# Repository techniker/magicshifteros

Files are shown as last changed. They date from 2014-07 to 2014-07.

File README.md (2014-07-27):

# MagicShifterOS #

Everything you need to modify and customize your MagicShifter

The most important directories are:

### /Case ###
All source (OpenSCAD + dxf) and STL files for the case and the first MagicShifter accessory: a bike mount.

### /Electronics ###
The original EAGLE design files of the MagicShifter PRO board (CC BY-NC-SA 3.0 http://creativecommons.org/licenses/by-nc-sa/3.0/), a PDF of the scematics and the BOM (Bill of Material) that documents every single resistor, capacitor, connector and IC I used in the design. I chose the CC BY-NC-SA to prevent crappy rip off copies. We use very high quality components from Osram, Cree, Texas Instruments, Freescale, austriamicrosystems, etc. and I fear in cheap MagicShifter clones these will be replaced by inferior replacements. If you make a true derivative of the design I will happily grant almost any exception to the license (free of charge of course) since I was hoping to spark a new wave of small, smart, embedded ultra low power systems for gaming, fashion & lighting with the release of my MagicShifter design :) 

I tried to give full credit to all the open source designs that influenced the MagicShifter design. If I forgot to reference any project please send me an email so that I may correct that mistake.

### /Firmware ###
Here is the code and the Makefile (generously written by Clifford Wolf http://www.clifford.at/). 

To build the firmware you have to copy the unzipped arduino software into a (not version controlled) "arduino" subfolder in the "Firmware" folder to compile the firmware yourself. Arduino is required since we use the Arduino USB implementation. 

If you don't want to build the firmware yourself you can use the precompiled HEX file in the "precompiled" subdirectory.

### /Software 
in the python subfolder you can find the tools for uploading custom images and custom firmware

* * *

please report any bugs you find in the ticket system or just send me a mail to:

wizards23+magicshifter@gmail.com

* * *

greetings from the future!

Philipp aka wizard23 aka babygiraffe

:: open source hardware/magic

:: http://magicshifter.net/

:: http://metalab.at/

Any sufficiently advanced technology is indistinguishable from a MagicShifter.

--Arthur C. Clarke

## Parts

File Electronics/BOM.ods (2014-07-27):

Nr | Name | Qty | Type | desc | rating | footprint | manufacturer | manuf. nr.
1 | BCENT, BON | 2 | OTHER | tactile switch, side, high reliability | B3F-3122 | B3F-31XX | Omron | B3F-3122
2 | BOFF, BRESET | 2 | OTHER | tactile switch, ultrasmall | B3U-1000P | B3U-XXXX | Omron | B3U-1000P
3 | C1, C2, C3, C4, C201, C301, C601, C602, C901, C903, C904, C905 | 12 | Capacitor |  | 100nF/25V/X7R | C0603
4 | C102, C103 | 2 | Capacitor |  | 2.2uF/16V/X7R | C0805
5 | C104, C105 | 2 | Capacitor |  | 10nF/25V/X7R | C0603
6 | C106, C304 | 2 | Capacitor |  | 47nF/25V/X7R | C0603
7 | C5, C6, C101, C661, C662, C663, C664, C665, C666, C701, C702, C801, C802 | 13 | Capacitor |  | 1uF/16V/X7R | C0603
8 | C7, C8 | 2 | Capacitor |  | 22pF/50V/NP0 | C0603
9 | C803 | 1 | Capacitor |  | 22uF/6.3V/ | C0805
10 | C902 | 1 | Capacitor |  | 4.7uF/10V/X7R | C0805
11 | D1, D2 | 2 | Diode | DUAL DIODE | BAV170,215 | SOT23 | NXP | BAV170,215
12 | FET1, FET3 | 2 | IC | N-mosfet | N Mosfet | SOT23 | Infineon | BSS123
13 | FET2 | 1 | IC | N/P dual mosfet | N/P Dualmosfet | SOT363 | DiodesZetex | DMG1016UDW-7
14 | LEDCHRG, LEDDEBUG | 2 | Diode | Blue LED | Blue, >40mcd@20mA | LED0603
15 | LEDFULL | 1 | Diode | Green LED | Green, >40mcd@20mA | LED0603
16 | LEDIR | 1 | Diode | Infrared LED | IR | LED1206 | Everlight | HIR11-21C/L11/TR8
17 | LEDON, LEDTX | 2 | Diode | Red LED | Red, > 40mcd@20mA | LED0603
18 | LEDRGB1 – LEDRGB16 | 16 | Diode | RGB LED | RGB | 5050 | Cree | CLV6A-FKB-CK1P1G1BB7R3R3
19 | LEDRX | 1 | Diode | Yellow LED | Yellow, >40mcd@20mA | LED0603
20 | LEDUV | 1 | Diode | UV LED | UV | LED1206 | Bivar | SM1206UV-395-IL
21 | LEDWHITE | 1 | Diode | White LED | OSLON | OSLON | Osram OS | LUW CN5M-GAHA-5P7R-1
22 | R1, R4, R6, R103, R108, R114, R119, R302, R805 | 9 | Resister |  | 1K/5%/0.1W | R0603
23 | R101, R102, R802 | 3 | Resister |  | 22R/5%/0.1W | R0603
24 | R104 | 1 | Resister |  | 47K/5%/0.1W | R0603
25 | R107, R110 | 2 | Resister |  | 22K/5%/0.1W | R0603
26 | R111, R116, R118, R120, R201, R202, R603, R804 | 8 | Resister |  | 100K/5%/0.1W | R0603
27 | R112 | 1 | Resister | ref Va | 330K/1%/0.1W | R0603
28 | R113 | 1 | Resister | ref Vb | 560K/1%/0.1W | R0603
29 | R13, R14, R15 | 3 | Resister |  | 330R/5%/0.1W | R0603
30 | R2, R3, R106, R703, R704, R705 | 6 | Resister |  | 10K/5%/0.1W | R0603
31 | R601, R602 | 2 | Resister | rgb ref | 2K/1%/0.1W | R0603
32 | R701 | 1 | Resister | uv ref | 15K/1%/0.1W | R0603
33 | R702 | 1 | Resister | white ref | 6K8/1%/0.1W | R0603
34 | R8, R9, R105, R117 | 4 | Resister | R105: chrgref; R117: tchrgref | 4K7/1%/0.1W | R0603
35 | R801 | 1 | Resister |  | 1M/5%/0.1W | R0603
36 | R803 | 1 | Resister |  | 47R/5%/0.1W | R0603
37 | UCACCEL | 1 | IC | 3 Axis Accelerometer | Accelerometer | QFN-16 | Freescale | MMA8452QT
38 | UCATMEL | 1 | IC | uC, Atmega32U4-MU | uC | QFN-44 | Atmel | Atmega32U4-MU
39 | UCCHRG | 1 | IC | Lipo Charger | Lipo charger | SOT23-5 | Microchip | MCP73831T-2ACI/OT
40 | UCEEPROM | 1 | IC | SPI EEPROM 1MBt | SPI EEPROM | SOIC-8/150mil | Microchip | SST25VF080B-80-4I-SAE
41 | UCL1, UCL2 | 2 | IC | LED Driver | LED Driver | SOT23-6 | Adv. Analogic Tech. | AHK3292IGU-T1
42 | UCLSEN | 1 | IC | RGBV Light Sensor with Prox. | RGBV Sensor | FN-6 | AMS | TCS37717FN
43 | UCRGB1, UCRGB2 | 2 | IC | 24 Ch. Led Driver | LED Driver | QFN-32 | Texas Instruments | TLC5947RHBT
44 | UCRTC | 1 | IC | I2CTM Real-Time Clock | I2C_RTC | MSOP-8 | Microchip | MCP79410-I/MS
45 | UCVRG | 1 | IC | VOLTAGE REG | VREG | SOT23-5 | Microchip | MCP1824T-3302E/OT
46 | XLIPO1 | 1 | Connector | Through-hole type shrouded header, SIDEENTRY, 2mm | S 2B-PH-K-S | pin_2x2mm | JST | S 2B-PH-K-S
47 | XUSB | 1 | Connector | USB micro AB conn, SMD | USBAB | SMD | FCI | 10104111-0001LF
48 | Y1 | 1 | OTHER | Crystal, SMD-5X3 | 8MHz/30ppm/12pF/ | SMD-5X3.2mm | Interquip | 5RCA08000123TF80Q3
49 | Y2 | 1 | OTHER | Crystal, THRU-HOLE | 32.768kHz/20ppm/12pF/50K | NC26LF | Fox Electronics | NC26LF-327

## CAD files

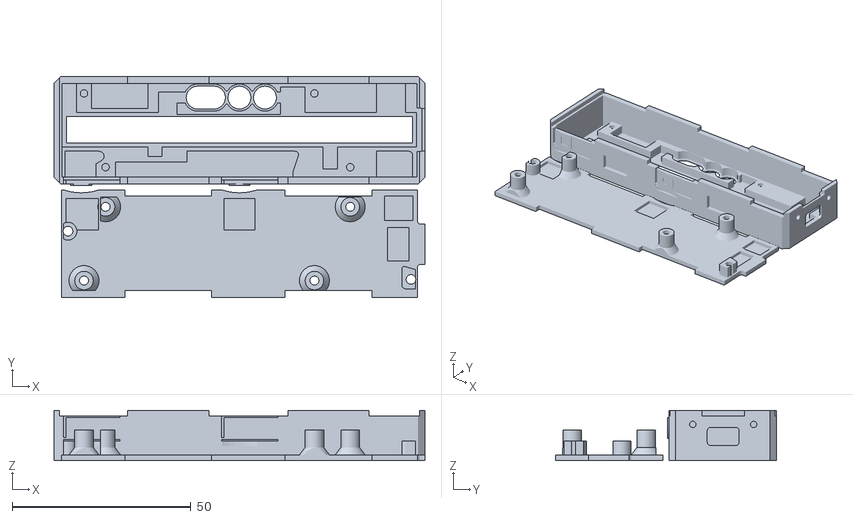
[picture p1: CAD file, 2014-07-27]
Case/magicshifter_case_100.stl
103.7 x 61.8 x 14.0

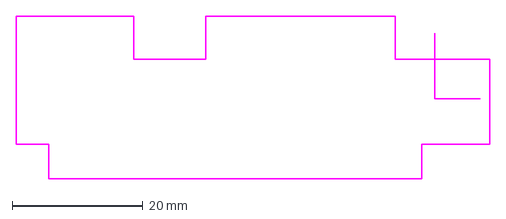
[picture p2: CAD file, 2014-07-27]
Case/magicshifter_case_87.dxf
72.4 x 24.9 mm

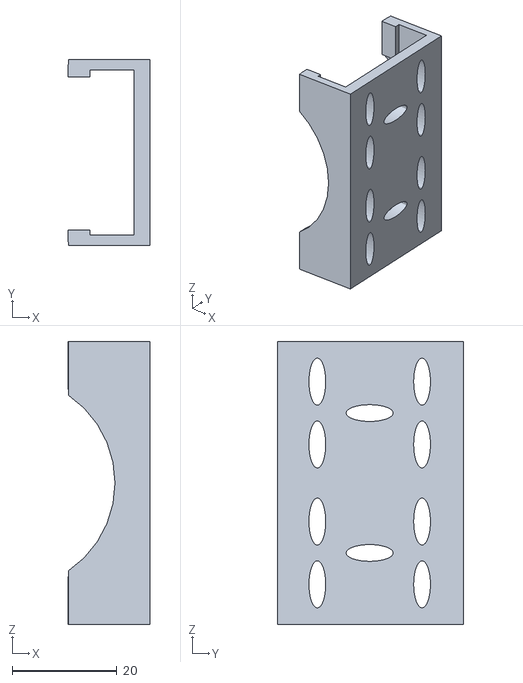
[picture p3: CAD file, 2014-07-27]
Case/magicshifter_case_95_bikesnap.stl
15.6 x 35.5 x 54.0

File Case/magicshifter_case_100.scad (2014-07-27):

/*
 * MagicShifter Case Prototype
 * Copyright (C) 2013  Philipp Tiefenbacher <wizards23@gmail.com>
 *
 * This program is free software; you can redistribute it and/or modify
 * it under the terms of the GNU General Public License as published by
 * the Free Software Foundation; eitd2her version 2 of the License, or
 * (at your option) any later version.
 *
 * This program is distributed in the hope that it will be useful,lp
 * but WITHOUT ANY WARRANTY; without even the implied warranty of
 * MERCHANTABILITY or FITNESS FOR A PARTICULAR PURPOSE.  See the
 * GNU General Public License for more details.
 */

// the name of the file that is used for all 2D geometry
dxfFileName = "magicshifter_case_100.dxf";

// if true build plate will be generated; if false assembled model is generated 	
forPrint = true;

preview = false;

// set to true or false depending on what part you want to make
generateBottomPart	= true;
generateTopPart 	= true;
generateButtonCover = false;

// print quality/detail level of cirlces 
$fn=preview ? 8 : 32;

// height of the bottom layer of the bottom part (which is the side you see when you look at the LEDs
floorH=0.5;

// height of the 2nd layer from the bottom (the layer the pcb rests on); it has holes where components are on the bottom side of the PCB

foilH = 0.3;
pcbToFloorH = 2.5 + 0.75 + foilH - 0.6;

// height of the magicshifter pcb (without components)
pcbHeight=1.75;

// the height of the lid (lid == topPart)
lidH = 1.6;

lidHollow = 1.1;

// total height of assembled case
totalH=14; 

pillarCutH = 5.5;


// should be larger than the largest dimension of the case (used in the 2D to 3D conversion), no need to change this 
infSize = 500;

///////////////////////////////////////////////////////////////////////

// height of the button cover (derived from totalH and the other heights)
buttonH = totalH - (pcbToFloorH+floorH+pcbHeight+lidH);

pillarH = totalH-(pcbToFloorH+floorH+pcbHeight+0.3);

////////////////////////////////////////
// the actual parts
////////////////////////////////////////

// bottom part (the one the pcb is in facing with the LEDs down and the 


*union()
{
	translate([0,0*32,0]) render() mirror([0,1,0]) topPart();
	translate([0,1*32,0]) render() mirror([0,1,0]) topPart();
	translate([0,2*32,0]) render() mirror([0,1,0]) topPart();
	translate([0,3*32,0]) render() mirror([0,1,0]) topPart();
}

*union()
{
	translate([0,0*32,0]) render() bottomPart();
	translate([0,1*32,0]) render() bottomPart();
	translate([0,2*32,0]) render() bottomPart();
	translate([0,3*32,0]) render() mirror([0,1,0]) topPart();
	
	translate([-20,0,0]) rotate([0,0,90]) render() mirror([0,1,0]) topPart();
	
	translate([-20-32,0,0]) rotate([0,0,90]) render() mirror([0,1,0]) topPart();
}



*rotate([0,0,90]) for (i = [0:1])
{
	translate([i*64, 0,0]) completeCase();
}

translate([65, -20,0]) rotate([0,0,90]) completeCase();

// button cover (TODO: assembled view of this)
if (generateButtonCover) extrudeLayer("buttoncover", buttonH);




module completeCase()
{
	render()

	rotate ([0,0,90])
	{
		if (generateBottomPart) bottomPart();
		
		// top part (the lid with the pillars); top part is mirrored to make drawing the dxf easier
		if (generateTopPart)
		{
			if (forPrint) translate([0,32,0]) mirror([0,1,0]) topPart();
			if (!forPrint) translate([0,0,totalH]) mirror([0,0,1]) topPart();
		}
	}
}

/////////////////////////////////////////
// main modules
/////////////////////////////////////////

module bottomPart()
{
	difference()
	{
		union()
		{
			// the pcb rests on this 
			extrudeLayer("bottom_floor_pcb", floorH+pcbToFloorH,0);
	
			// main part of case
			difference() 
			{
				// outher shape of case
				union() {
					extrudeLayer("bottom_floor", totalH, 0);
					translate([0,0,pcbToFloorH+floorH+pcbHeight]) fromDXF_XY_XZ("button_text_xy", "button_text_xz");
				}
				// cut out the size of pcb
				extrudeLayer("pcb_cutout", totalH, floorH);
				//#extrudeLayer("button_cutout", totalH, pcbToFloorH+floorH+pcbHeight+0.6);

#translate([0,0,pcbToFloorH+floorH+pcbHeight]) fromDXF_XY_XZ("button_cutout_xy", "button_cutout_xz");
	
				// cut out buttons and USB connector extra space
				//*extrudeLayer("side_cutouts", totalH, floorH+pcbToFloorH+pcbHeight);
				
				// cut out indents in the case where accessories are inteded to snap fit onto
				translate([0,0,totalH/2]) fromDXF_XY_XZ("schnappen_halter_xy", "schnappen_halter_xz");		
			}
		}
		// snap cutouts
		union() 
		{
			translate([0,0,pcbToFloorH+floorH+pcbHeight]) fromDXF_XY_XZ("button_slits_xy", "button_slits_xz");
			// we need this intersection because to limit the cutout to the height of the lid
			*intersection()
			{
				// the cutout on the sides where the lid should snap fit in
				translate([0,0,totalH]) fromDXF_XY_XZ("lid_snap_cut_xy", "lid_snap_cut_xz");
				// limit the cutout to height of lid 
				cubeEx([infSize,infSize,lidH*2], [0,0,0.5], [0,0,totalH-lidH]); 
			}
			// hole in case for USB connector also includes small holes for attaching a string
			// TODO: hackish because of the positioning, clean up
			extrudeLayerLeft("bottom_cut_left_zy", 10, zOffset=floorH+pcbToFloorH+pcbHeight, xOffset=0);
			// cut out the space where the lid fits in on top
			extrudeLayer("lid_cut", totalH, totalH-lidH);
			*translate([0,0,totalH-lidH]) fromDXF_XY_ZY("lidholder_cutout_xy", "lidholder_cutout_zy");
			extrudeLayer("button_freedom", totalH, totalH-(lidH+0.3));
		}

		//#extrudeLayer("button_indent_xy", lidH,pcbToFloorH+floorH);
//#extrudeLayer("button_indent_xz", 3*totalH,-1);
		translate([0,0,pcbToFloorH+floorH+pcbHeight])  fromDXF_XY_XZ("button_indent_xy", "button_indent_xz", $fn=64);


	// screwholes 
		for (pos = cylPositions) {
			translate([pos[0], pos[1], floorH]) {
				cylinder(r= 1.05, h = totalH, center=false);
			}
		}
	}
}

cylPositions = [
//[85.8,9.5],
  [86.803053, 10.45868], // at bowwerbutton
 [92.8355, -10.1573],
 [18.4147, 10.4587],
 //[8.405193, -10.15731],
 [28.405193, -10.15731],
 //[6.34989, -8.25234]. // over reset
];

microButtonPositions = [
[1.418143, -9.839815],
[97.3138, 3.654232]
];



module topPart()
{
	difference() {
		union()
		{
			difference()
			{
				// this intersection is needed to get a clean model
				intersection()
				{
					union()
					{
						// the main part of the lid
						extrudeLayer("lid", 4*lidH,-2*lidH);
						// the small snapping parts on the side
						*fromDXF_XY_XZ("lid_snap_xy", "lid_snap_xz");
						*translate([0,0,lidH]) mirror([0, 0, 1]) fromDXF_XY_ZY("lidholder_xy", "lidholder_zy");
					}
					// limit bottom pat of the lid to lidH
					cubeEx([infSize,infSize,lidH], [0,0,0.5], [0,0,0]); 
				}
				extrudeLayer("lid_hollow", 10,lidH-lidHollow);
			}
			difference()
			{
				extrudeLayer("pillars", pillarCutH,0);
				//extrudeLayer("pillars", totalH-(pcbToFloorH+floorH+pcbHeight),0);
				//extrudeLayer("pillars_cutaway", totalH, pillarCutH);
			}
			intersection()
			{
				
				for (pos = cylPositions) {
					translate([pos[0], pos[1], lidH/2]) cylinder(r1= 4.5+0.3, r2=0, h = 6+0.3);
					translate([pos[0], pos[1], lidH/2]) cylinder(r= 2.6, h = pillarH);
				}

				extrudeLayer("lid_crop", pillarH, 0);
			}
			
		}
		// screwholes and versenkte schraubenkoepfe ;)
		for (pos = cylPositions) {
			translate([pos[0], pos[1], -1]) {
				cylinder(r= 1.25, h = 3*totalH, center=true);
				cylinder(r1= 3.4+0.3, r2= 0, h = 3.4+0.3, center=false);
			}
		}
		for (pos = microButtonPositions) {
			translate([pos[0], pos[1], -1]) {
				cylinder(r= 1.35, h = 3*totalH, center=true);
			}
		}

if (!preview)
{
		extrudeLayer("logo", 1.3,-1, $fn=16);

		extrudeLayer("logo2", 1.3,-1, $fn=16);
}

			extrudeLayer("button_indent_xy", 3*totalH,-1, $fn=64);
	}
}

/////////////////////////////////////////
// helper modules
/////////////////////////////////////////

/* 
constructs a 3D object by extruding the given layers of the dxf file 
layerXY is extruded in Z axis
layerZY is extruded in the X axis
*/
module fromDXF_XY_ZY(layerXY, layerZY)
{
	intersection()
	{
		linear_extrude(convexity = 10, height = infSize, center = true)
			import_dxf(file = dxfFileName, layer = layerXY, convexity = 10, scale=1);
		rotate([0,-90,0]) linear_extrude(convexity = 10, height = infSize, center = true)
			import_dxf(file = dxfFileName, layer = layerZY, convexity = 10, scale=1);
	}
}

module fromDXF_XY_XZ(layerXY, layerXZ)
{
	intersection()
	{
		linear_extrude(convexity = 10, height = infSize, center = true)
			import_dxf(file = dxfFileName, layer = layerXY, convexity = 10, scale=1);
		rotate([90,0,0]) linear_extrude(convexity = 10, height = infSize, center = true)
			import_dxf(file = dxfFileName, layer = layerXZ, convexity = 10, scale=1);
	}
}
module fromDXF_XY_ZY_XZ(layerXY, layerZY, layerXZ)
{
	intersection()
	{

linear_extrude(convexity = 10, height = infSize, center = true)
			import_dxf(file = dxfFileName, layer = layerXY, convexity = 10, scale=1);
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

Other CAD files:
Case/magicshifter_case_87_single.stl
Case/magicshifter_case_87.scad
Case/magicshifter_case_95_bikesnap.scad
Case/magicshifter_case_100.dxf

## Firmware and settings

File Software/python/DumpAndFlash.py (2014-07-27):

import os
from MagicTest import *


if __name__ == '__main__':
	shifterNr = -1
	doDump = True
	doFlash = True	
	doBitmaps = True
	device = ""	

	if (len(sys.argv) >= 2):
		shifterNr = int(sys.argv[1])
	if (len(sys.argv) >= 3):
		device = sys.argv[2]
	if (len(sys.argv) >= 5):
		doDump = int(sys.argv[3])
		doFlash = int(sys.argv[4])
	if (len(sys.argv) < 2):
		print "usage:"
		print "python DumpAndFlash.py nrOfShifter [serialdevice] [doDump (default 1)] [doFlash (default 1)]"
		print "example: DumpAndFlash.py 123 1 1"
		print "the aboce command line would dump and flash the shifters using serial number 123 (increasing it 1 for every shifter"
		exit()

	if (not doDump) and (not doFlash):
		print "don't dump and don't flash...nothing to do" 
		exit()

	while (1):
		pOK("Ready to dump and flash MagicShifter Nr: " + str(shifterNr) + " (ESC to cancel)")
		key = read_single_keypress()
		if (ord(key) == 27):
			exit()

		if (doDump):
			continueDump = 3
		else:
			continueDump = 0
		while (continueDump):
			fi, fo, fe= os.popen3("python MagicTest.py dump " + device)
			stderr = fe.readlines()
			stdout = fo.readlines()
			print stdout[0]
			if (stdout[0].find("NR_COLOR_TESTS") != -1 and stdout[0].find("ACC") != -1 and stdout[0].find("EOD") != -1):
				dumpName = "./dumpof500/shifter_%04d.txt" % (shifterNr)
				pOK("writing dump file: " + dumpName)
				if (os.path.exists(dumpName)):
					pFail("Dump file already exists! " + dumpName)
					exit()
				else:
					file = open(dumpName, 'wt')
					file.write(stdout[0])
					file.close()
					pOK("writing dump complete")
				continueDump = 0
			else:
				pFail("dump not working, press key to continue esc to stop")
				key = read_single_keypress()
				if (ord(key) == 27):
					exit()
				continueDump = continueDump - 1

		dmesgClear()

		if doFlash:
			print "--> Press the RESET button"
			cnt = 0
			while (not dmesgPing()):
					sleep(0.1)
					cnt = cnt + 1
					if (cnt > 1000):
						pFail("Reset Button was not pressed within 100 seconds. Is it broken?")
						exit()
			pOK("Reset Button OK!")
			sleep(1)
			pOK("programming device...")
			if(callProgrammer()):
				pOK("bootloader OK! :)")
			else:
				pFail("USB connection does not work or Bootloader is not responding. :(")
				exit()
			sleep(1)
		
		if (doBitmaps):
			continueBitmaps = 3
			while (continueBitmaps):
				print "Uploading Bitmaps (takes some seconds be patient)"
				fi, fo, fe = os.popen3("./UploadCree.sh " + device)
				#fi, fo, fe = os.popen3("./UploadCree_Makerbot.sh")
				#fi, fo, fe = os.popen3("./UploadCree_Makerbot_small.sh")
				stderr = fe.readlines()
				stdout = fo.readlines()
				print stdout
				countBitmaps = 0
				for line in stdout:
					countBitmaps += line.count("READBACK @sector")
				if (countBitmaps != 18):
					pFail("OH noes uploading bitmaps failed (enter to continue exc to exit) == " + str(countBitmaps))
					key = read_single_keypress()
					if (ord(key) == 27):
						exit()
					continueBitmaps = continueBitmaps - 1;
				else:
					continueBitmaps = 0
			

		shifterNr += 1

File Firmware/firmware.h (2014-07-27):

#ifndef FIRMWARE_H
#define FIRMWARE_H

#define ATMELSTUDIO_HACK

#include <Arduino.h>
#include <EEPROM.h>
//#include <Wire.h>

//#define BABYSHIFTER
//#define NOSERIAL

//#define UNITTEST
//#define DEBUGMODE

// TO prevent accidental blindness by 
#define EYE_FRIENDLY

// customize your own name ;)
#define CUSTOMIZED_NAME "Shifter"

#define LEDS 16
// used for fixed point arithmetic
#define FIXED_SHIFT 8
// make columns longer
#define COLUMNMULTIPLY 2
#define ANIMATIONDELAY 2


// chinese LEDS
//#define COLOR_CODING_GRB
// cree LEDS
#define COLOR_CODING_RGB

#ifdef COLOR_CODING_RGB
	#define CHANNEL_RED 		0
	#define CHANNEL_GREEN 	1
	#define CHANNEL_BLUE 	2
#endif
#ifdef COLOR_CODING_GRB
	#define CHANNEL_RED 		1
	#define CHANNEL_GREEN 	0
	#define CHANNEL_BLUE 	2
#endif

/* Pin definitions */
#ifdef BABYSHIFTER
  #define XAXIS 1
  #define YAXIS 0
  #define ZAXIS 2
    
  #define ledPin 11
  
  #define int1Pin 12 // D7  // Baby Shifter  
  #define int2Pin 13 // B4
  
  #define BTNC 8
  
  #define TXLED1 
  #define TXLED0
#else  
  #define RTCINT_PIN A2
  #define IRPWM_PIN 5 // PC6/pin 31 

  #define XAXIS 0
  #define YAXIS 1
  #define ZAXIS 2
  
  #define ledPin  13
  
  #define int1Pin 8  // Magic Shifter  
  #define int2Pin 9

  #define int3Pin 0 // light sensor

  #define EEPROM_CS_PIN 11
  
  #define BTNC 10
#endif

#define LEDWHITE_PIN 6
#define LEDUV_PIN 1


#define RXLED 17
#define PWRMGT A5
#define PWRMGT_ANALOG_PIN 5
#define LEDTESTER_ANALOG_PIN 2

#define CHRGSTAT_PIN A4
#define TURBOCHRG_PIN 7
//#define SHIFT_OUT_PIN 6

#define AUTOSHUTDOWN_TIME (23*60*1000L)  // shuts down automatically after 5 minutes

#define SHUTDOWN_TIME 2000
#define MODE_EXIT_TIME 2000
#define DEBOUNCE_TIME 15
#define LONG_CLICK_TIME 550

#define BrightnessCtrlTime 600

// TODO
#define DOUBLE_CLICK_TIME 250
#define REWARD_FLASH_LEN 350

#define POWERUP_USER 0
#define POWERUP_USB 1
#define POWERUP_ALERT 2

// global Startup state
extern byte powerupReason;

// global ButtonState
extern long powerBtnPressed;
extern int powerBtnClickedTime;
extern int powerBtnReleased;
extern long centerBtnPressed;
extern int centerBtnClickedTime;
extern int centerBtnReleased;

extern long lastActivity;

// define global LED state
extern uint8_t LEDS_VALUES[];

// global Accelerometer state

extern byte data[6];  // x/y/z accel register data store here
extern int accelCount[3];  // Stores the 12-bit signed value

extern byte orientation;
extern byte orientationFace;
extern byte zTilt;
extern int8_t xTaps, yTaps, zTaps;
extern uint8_t lastTapStatus;
extern byte lastTransientStatus;

//#define SHAKEDEBUG
//#define FRAMEDEBUG
#define LASTINTERRUPTTIMEOUT 8

// rtc state
extern uint8_t initiateRTCReadout;
extern uint8_t rtcBuffer[];

// brightness and mode
extern int ad;
extern uint8_t v;
extern uint8_t MAXMV;
extern bool vChanged;

// light sensor state
extern int cs, rs, gs, bs, ps;
extern int lightSensorValues[5];


union MSColor {
#ifdef COLOR_CODING_RGB
  struct { uint8_t r, g, b; } rgb;
#endif
#ifdef COLOR_CODING_GRB
  struct { uint8_t g, r, b; } rgb;
#endif
  struct { uint8_t ch0, ch1, ch2; } ordered;
  uint8_t channels[3];
	
/*
	public MSColor(uint8_t _r, uint8_t _g, uint8_t _b)
	{
		rgb.r = _r;
		rgb.g = _g;
		rgb.b = _b;
	}
*/ 
 };

// MagicShifter.cc
struct MSBitmapHeader
{
	uint32_t eepromAddr;

	uint8_t pixelFormat;
	uint8_t maxFrame;
	uint8_t frameWidth;
	uint8_t frameHeight;

	uint8_t subType;
	uint8_t firstChar;
	uint16_t animationDelay;
} __attribute__((packed));
	
struct MSBitmap
{
	MSBitmapHeader header;
	MSColor color;
};

extern uint8_t AccelShakeNrOfFrames;
extern uint8_t AccelShakeFrameNr;
extern MSBitmap font16px;
extern MSBitmap font12px;
extern MSBitmap font8px;

//extern uint8_t fontWidth;
//extern uint8_t fontHeight;

void run_bootloader();
void MagicShifter_Init();
void blink(int p1, int p2, int n);
void SetDebugLeds(byte debug, byte rx, byte tx);
uint8_t SerialReadByte();
uint16_t SerialReadWord();
bool MagicShifter_Poll_Menue();
bool MagicShifter_Poll();
void USBPoll();
/*void LoadFont(uint8_t sector);
void PlotFont(uint8_t ascii, uint8_t column, uint8_t startLed);
void PlotText(char *text, uint16_t column, uint8_t startLed);
*/
void LoadBitmap(uint8_t sector, MSBitmap *bitmap);
void PlotBitmapColumn1Bit(const MSBitmap *bitmap, uint16_t absColumn, uint8_t ledIdx);
void PlotBitmapColumn24Bit(const MSBitmap *bitmap, uint16_t absColumn, uint8_t startLed);
void PlotBitmapColumn(const MSBitmap *bitmap, uint8_t frame, uint8_t column, uint8_t startLed);
void PlotText(const MSBitmap *bitmap, char *text, uint16_t column, uint8_t startLed);
void UpdateAccelShakeCurrentColumn();

void startToEndIndex2(int start, int end, int d, int index, int color);
void ackFlash(int r, int g, int b, int iS, int iE, int d1, int d2, int d3);
void debugColor(int r, int g, int b, int iS, int iE, int d);
void UpdateButtons();
void saveMode(int idx);
void saturateRgb(uint8_t &r, uint8_t &g, uint8_t &b);
void SetWhiteLED(uint8_t val);
void SetUVLED(uint8_t val);
void enableLeds(uint8_t val);


void CheckTCS3771(int cycles);
bool VerifyTCS3771Interrupt();
void PickupColor(uint8_t &byte_r, uint8_t &byte_g, uint8_t &byte_b);
void PickupColorEx(uint8_t cycles, uint8_t useLight);
byte xorshift32();


// MMA.cc
struct AccelConfig
{
	uint8_t accelInterruptNr, tapInterruptNr, transientInterruptNr;
	uint8_t accelScale;
	uint8_t accelDataRate;
};

void ClearInterruptI2CReadout();
void AccelSetup(AccelConfig *newConfig);
void BackupAccelState();
void RestoreAccelState();
void AccelPoll();
void initMMA8452(byte fsr, byte dataRate); // dericated
void MMA8452Active();
void MMA8452Standby();
void writeRegister(unsigned char address, unsigned char data);
void CheckMMA8452();
void CheckMMA8452WithInterrupts();
void CheckMMA8452Pulse();

void updateLedsWithBlank(); // depricated
void updateLeds(); // depricated

void setRGB(uint8_t index, uint8_t r, uint8_t g, uint8_t b);
void setAll(uint8_t r, uint8_t g, uint8_t b);
void setChannel(uint8_t index, uint8_t channelIndex, uint8_t value);
void setAllChannel(uint8_t channel, uint8_t value);

//void setPixel(byte index, byte r, byte g, byte b); // now only used in ledwarz
void Wheel(byte WheelPos, byte &r, byte &g, byte &b);

// TLC5947
void initLEDS();
void updateLeds(); // depricated
void updateLedsWithBlank(); // depricated

void updateLedsWithBrightness();
void latchLedsWithBlank();

byte readRegister(uint8_t address);
byte TCS3771_ReadRegister(byte address);
int loadMode();
int ModeSelector(int modes, int startIdx, char*text[]);

static bool waitButton();
void displayText(char *text, bool wait=true, MSBitmap *font = NULL, int posX=0);
void Int2Str(int val, char *text);
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
